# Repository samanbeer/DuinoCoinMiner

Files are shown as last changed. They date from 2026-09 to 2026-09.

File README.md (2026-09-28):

# DuinoCoinMiner



- **What is it?** It is a small PCB board with XIAO ESP32-C3 as main MCU for controlling 6 ATmega328P chips
- **What does it do?** It mines crypto currency called Duino Coin. Which is a specialized coin that can be mined on any device like arduinos and lot more. You read about it on their [site](duinocoin.com)

## Project Gallery

### 3D PCB Renders

<p align="center">
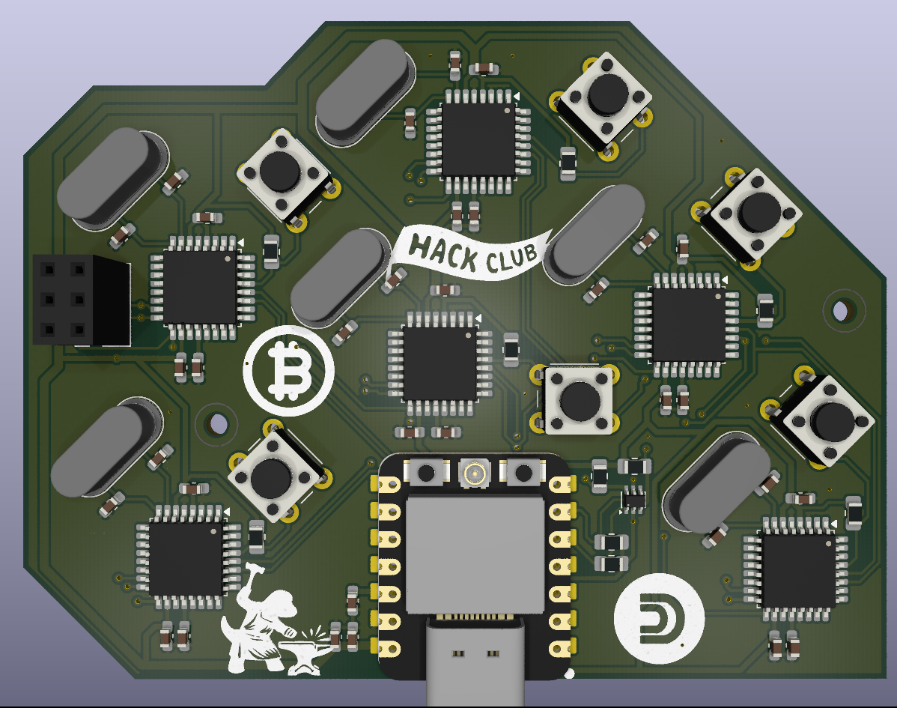
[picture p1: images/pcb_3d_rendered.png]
Rendered PCB Top
  
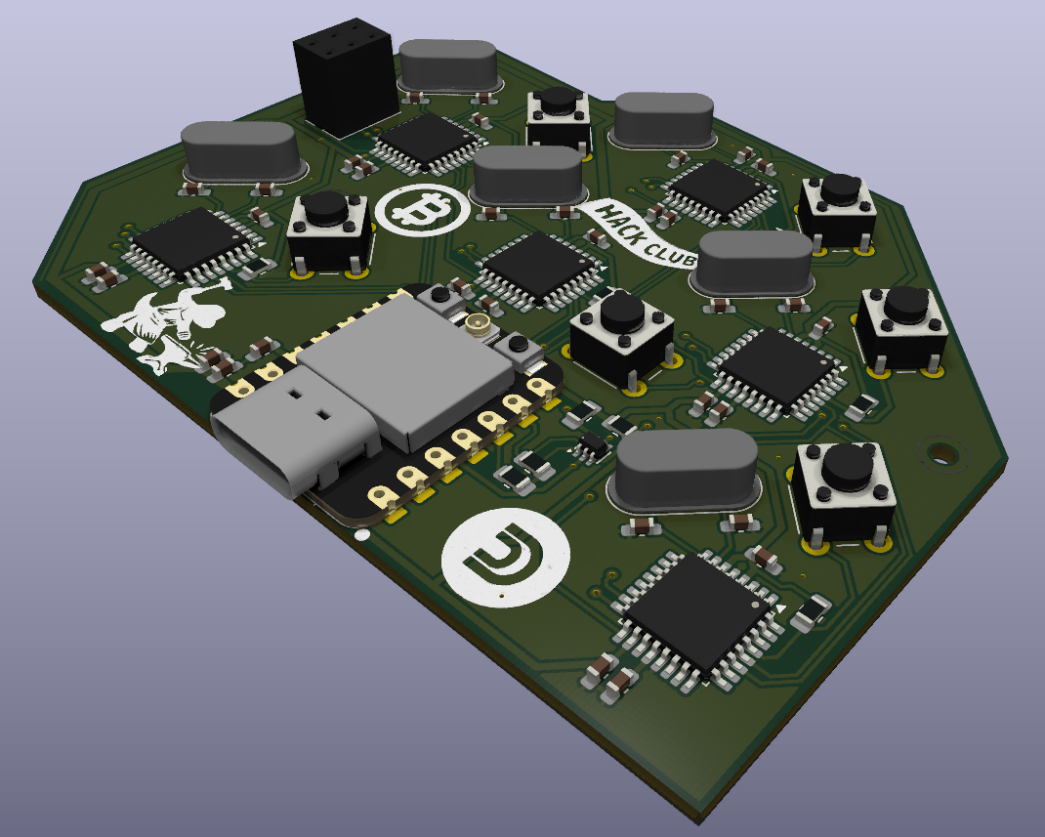
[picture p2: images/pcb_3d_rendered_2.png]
Rendered PCB Angle
  
</p>

### PCB Schematic and layout

<p align="center">
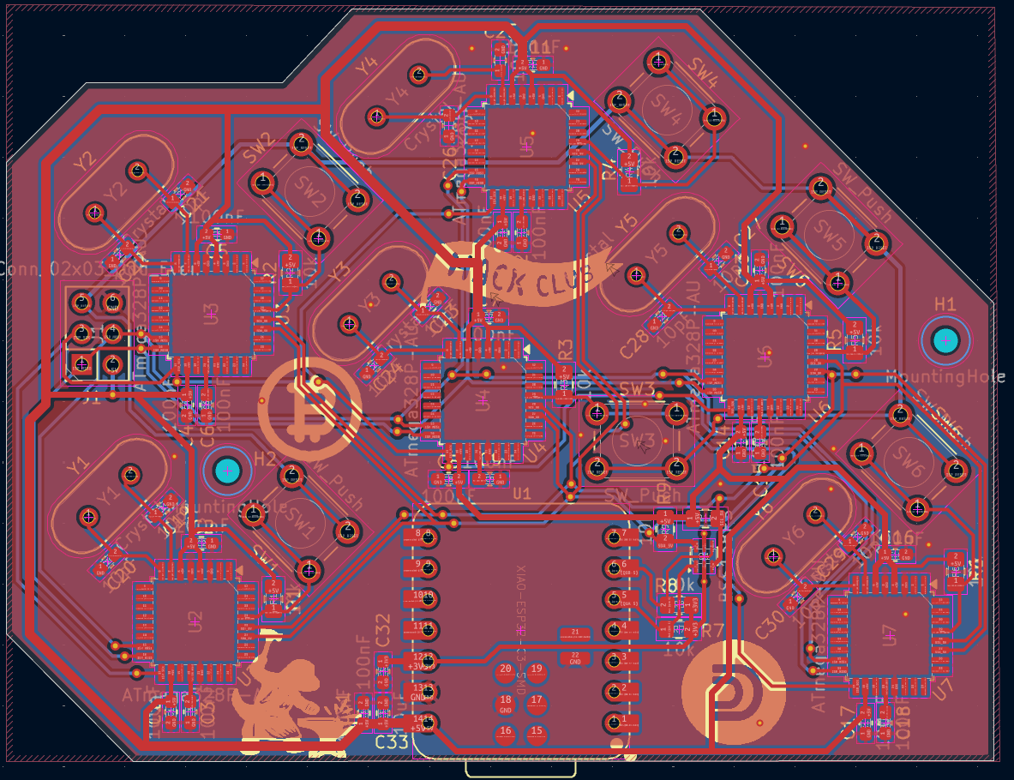
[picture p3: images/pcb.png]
PCB Layout
  
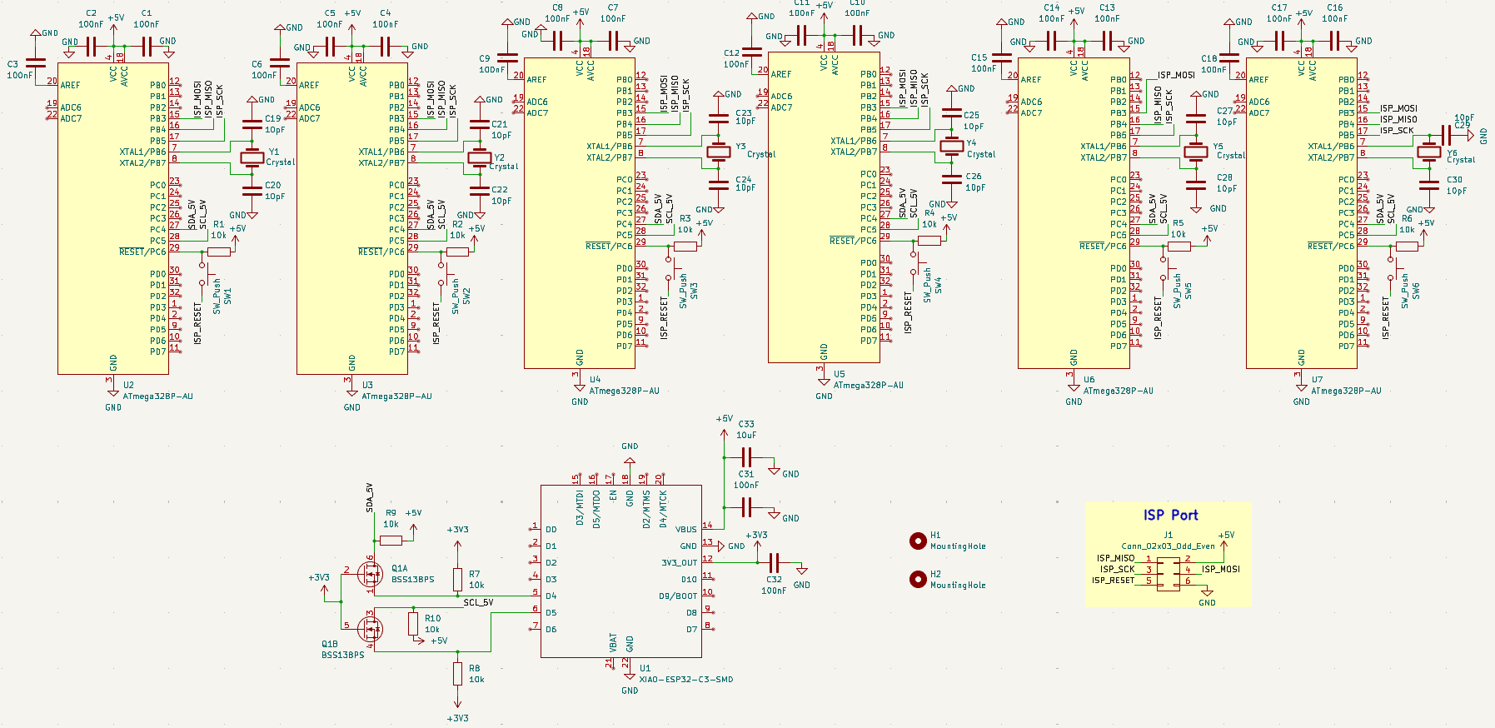
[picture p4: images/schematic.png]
Schematic Diagram
  
</p>

### 3D Enclosure (Fusion 360)

*3D printable case made in Fusion 360. All CAD and 3D model files (`.f3z`, `.step`) are in the [`CAD/`](CAD/) folder.*

<p align="center">
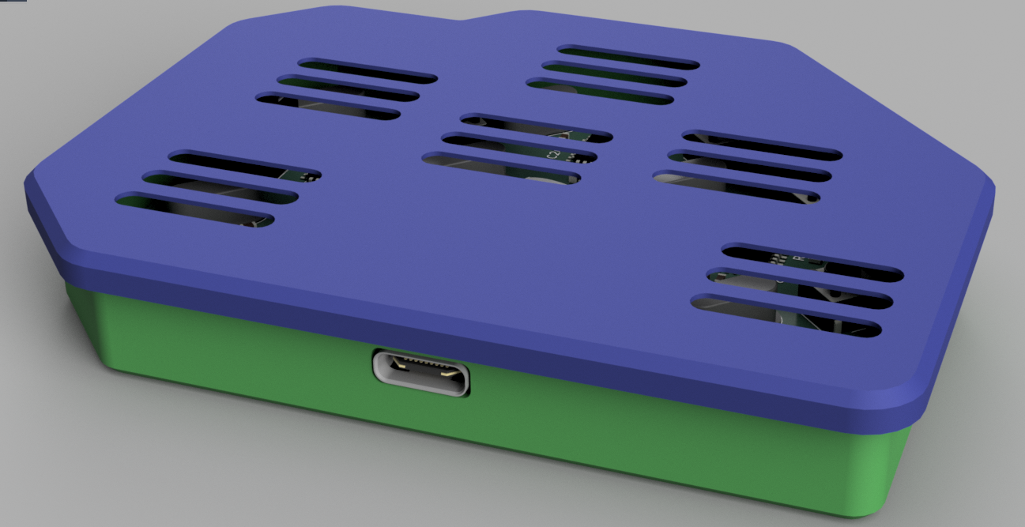
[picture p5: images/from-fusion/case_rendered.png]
Fusion 360 Case Render Front
  
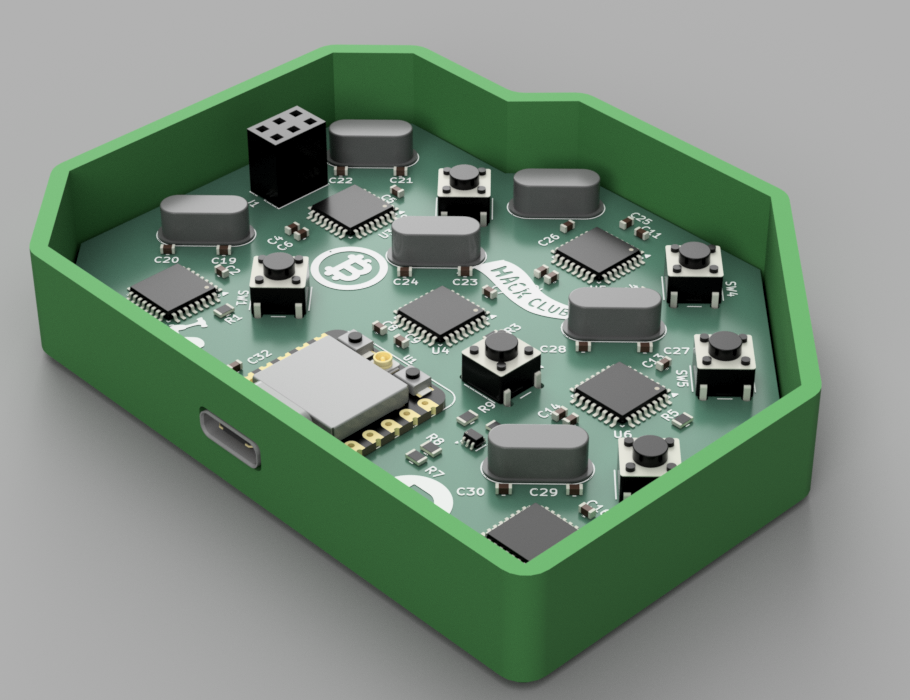
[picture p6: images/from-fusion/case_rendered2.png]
Fusion 360 Case Render Rear
  
</p>

<p align="center">
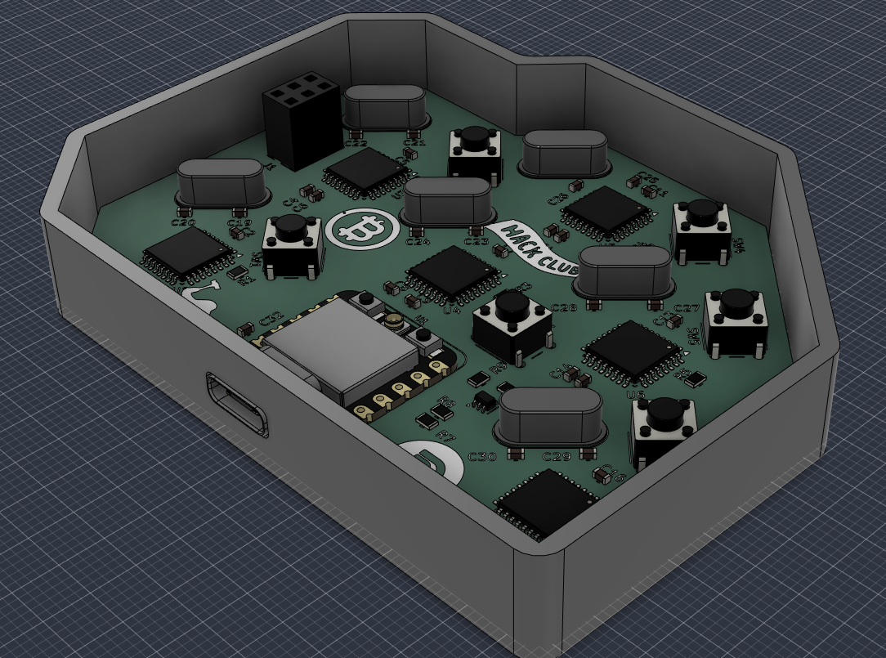
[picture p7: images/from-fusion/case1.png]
Fusion 360 Case Internal Assembly
  
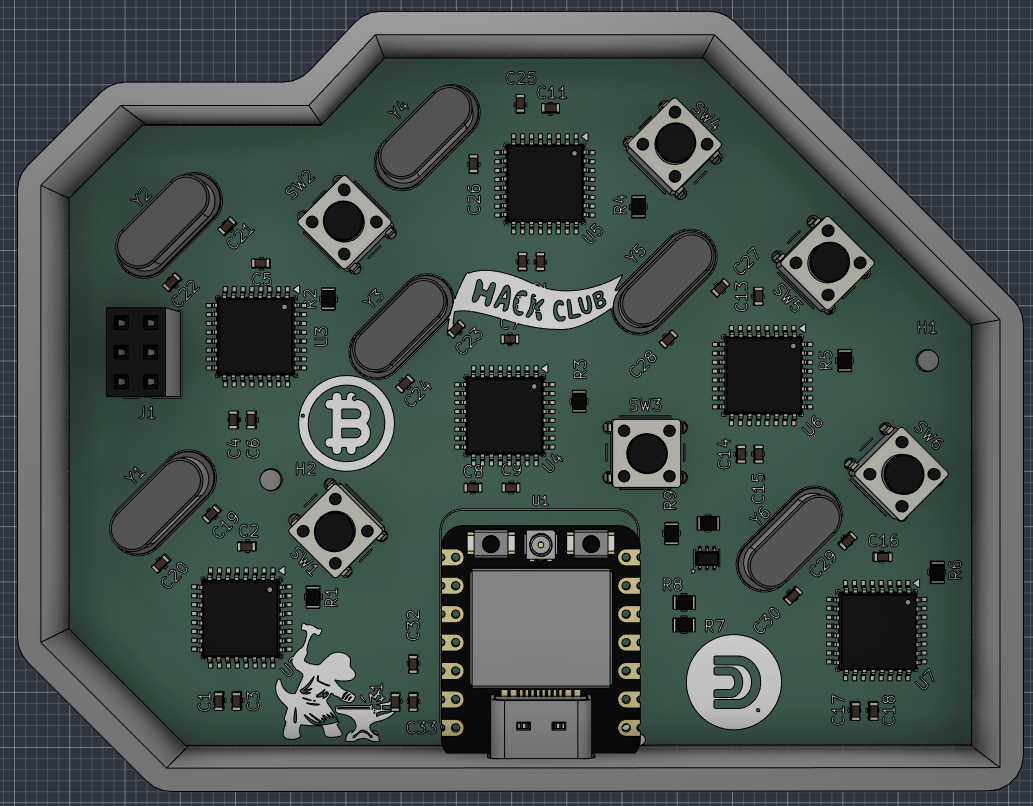
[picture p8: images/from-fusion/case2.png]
Fusion 360 Internal PCB Placement
  
</p>

<p align="center">
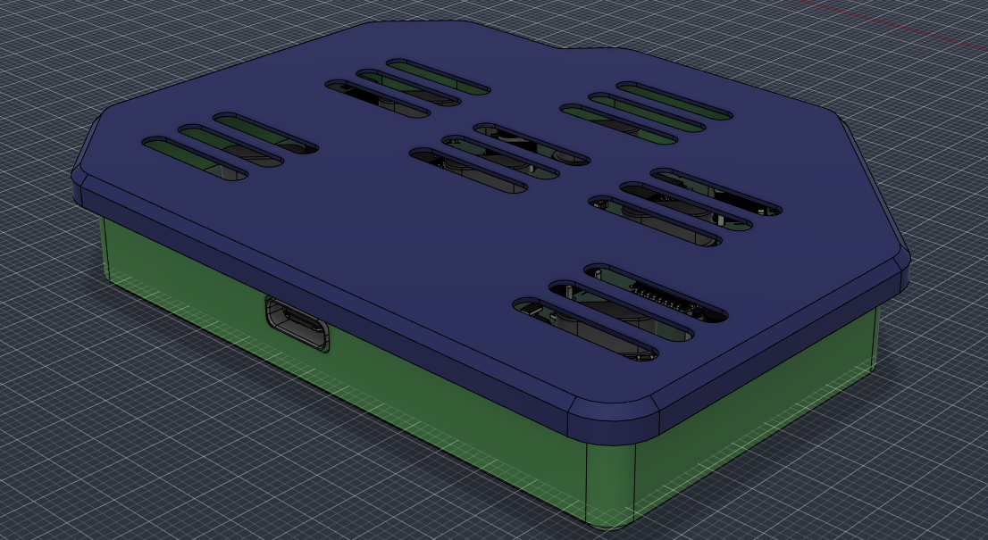
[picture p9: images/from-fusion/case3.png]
Fusion 360 Case Model View
  
</p>

---

### Required Tools & Materials

- Soldering iron
- Good solder wire
- Solder flux 
- small tweezers for picking small components like resistors and condenzators 
- 3D Printer for printing case from /cad folder

### Assembly Steps

1. **Start with the chips:**
   
   - **ATmega328P-AU** and **BSS138PS** .
   - It is best to solder these first while the board is clear of other bigger things.

2. **SMD Components:**
- - C1–C18, C31, C32 
  - C19–C30 
  - C33
  - R1–R10
3. **Main MCU:**
-     **Seeed Studio XIAO ESP32-C3**.
  - Solder the XIAO directly onto the PCB pads or solder pin headers so you can plug it in(not recommended)
4. **THT Components:**
-     **Crystals:** 20MHz crystals. Clip the leads, and solder from the bottom side.
  - **Switches:** 6x6mm reset buttons. Snap them into their holes and solder.
  - **ISP pin Header:** 2x3 pin header. Solder it to the board.
5. **Enclosure Assembly:**
-     3D print the bottom base (`case.step`) and the lid (`case_lid.step`). Files are in the /CAD folder.
  - Place PCB inside the bottom enclosure, with XIAO USB-C port aligned to the hole, and attach the lid.

---

## Firmware

Firmware files are located in "firmware" folder with README.md that contains guide how to flash the chips correclty and what you will need to install.

## BOM

| Reference | amount | Value / Component | Footprint / Package | Link | Cost (USD) |
| --- |:---:|:--- |:--- |:--- |:---:|
| **C1-C18, C31 and C32** | 20 | 100nF 50V | 0603 SMD | [TME Link](https://www.tme.eu/cz/details/0603b104k500ct/kondenzatory-mlcc-smd/walsin/) | $0.40 |
| **C19-C30** | 12 | 22pF 50V | 0603 SMD | [TME Link](https://www.tme.eu/cz/details/cc0603jrnpo9bn220/kondenzatory-mlcc-smd/yageo/) | $0.36 |
| **C33** | 1 | 10µF 10V | 0603 SMD | [TME Link](https://www.tme.eu/cz/details/lmk107bj106maltd/kondenzatory-mlcc-smd/taiyo-yuden/) | $0.12 |
| **J1** | 1 | 2x3 Pin Header | Pin header 2x03 (2.54mm) | [TME Link](https://www.tme.eu/cz/details/bl2-06g/dutinkove-listy/connfly/) | $0.35 |
| **Q1** | 1 | BSS138PS mosfet | SOT-363 | [TME Link](https://www.tme.eu/cz/details/bss138ps.115/tranzistory-s-polem-n-kanalove-smd/nexperia/) | $0.45 |
| **R1-R10** | 10 | 10kΩ | 0805 SMD | [TME Link](https://www.tme.eu/cz/details/crcw080510k0fkea/rezistory-smd/vishay/) | $0.14 |
| **SW1–SW6** | 6 | Switch (6x6mm, Height=5mm) | SW_PUSH_6mm_H5mm THT | [TME Link](https://www.tme.eu/cz/details/1825910-6/mikroprepninace-tact-tht/te-connectivity/) | $0.90 |
| **U1** | 1 | Seeed Studio XIAO ESP32-C3 | XIAO DIP/SMD Module | [TME Link](https://www.tme.eu/cz/details/seeed-113991054/vyvojove-kity-ostatni/seeed-studio/113991054/) | $6.36 |
| **U2-U7** | 6 | ATmega328P-AU (**20mHz**)  | TQFP-32 | [TME Link](https://www.tme.eu/cz/details/atmega328p-au/mikrokontrolery-avr/microchip-technology/) | $14.70 |
| **Y1-Y6** | 6 | 20MHz Quartz Crystal | HC-49/U THT | [TME Link](https://www.tme.eu/cz/details/49-20.000maaj-b/krystalove-rezonatory-tht/qst/) | $1.80 |
| **PCB** | 1 | 2 Layers | | [JLCPCB](https://jlcpcb.com) | ±$14 |
| **Shipping** | | Total Shipping | | TME and JLCPCB | $12.9 |
| **Total** | | | | | **52.48**  |

JLCPCB cart:



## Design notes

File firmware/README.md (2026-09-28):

# Firmware for DuinoCoinMiner

## 1. ATmega328P Nodes (`DuinoCoin_Arduino_Slave`)

### Required Arduino Libraries:

Install these libraries in your Arduino IDE via Library Manager or GitHub:

- [DuinoCoin](https://github.com/ricaun/arduino-DuinoCoin) (DUCO-S1A hashing engine)
- [ArduinoUniqueID](https://github.com/ricaun/ArduinoUniqueID) (Chip identifier)
- [StreamJoin](https://github.com/ricaun/StreamJoin) (StreamString for AVR)

### Flashing via ICSP (Connector J1):

1. Use an ISP programmer (e.g. **USBasp** or an **Arduino as ISP**).
2. Install the **[MiniCore](https://github.com/MCUdude/MiniCore)** board package in Arduino IDE:
   - Add `https://mcudude.github.io/MiniCore/package_MCUdude_MiniCore_index.json` to Additional Boards Manager URLs.
3. In **Tools** menu select:
   - **Board:** ATmega328P
   - **Clock:** External 20 MHz
   - **BOD:** 2.7V (or 4.3V)
   - **Compiler LTO:** Enabled
4. Click **Tools -> Burn Bootloader** to set the correct fuses for the 20MHz crystal.
5. Open `firmware/DuinoCoin_Arduino_Slave/DuinoCoin_Arduino_Slave.ino` and click **Sketch -> Upload Using Programmer**.

---

## 2. Master (`DuinoCoin_Esp_Async_Master`)

### Configuration:

Open `firmware/DuinoCoin_Esp_Async_Master/DuinoCoin_Esp_Async_Master.ino` and set:

```cpp
const char* ssid          = "Your_WiFi_SSID";      // Your Wi-Fi network name
const char* password      = "Your_WiFi_Password";  // Your Wi-Fi network password
const char* ducouser      = "Your_Username";       // Your Duino-Coin wallet username
const char* rigIdentifier = "DuinoMiner-6x";       // Custom name shown in web dashboard
```

### Required Arduino Libraries:

- [ArduinoJson](https://github.com/bblanchon/ArduinoJson) (v6.x)
- [AsyncTCP](https://github.com/me-no-dev/AsyncTCP)
- [ESPAsyncWebServer](https://github.com/me-no-dev/ESPAsyncWebServer)

### Flashing via USB-C:

1. Connect the Seeed Studio XIAO ESP32-C3 directly via USB-C to your computer.
2. In Arduino IDE:
   - Board: **XIAO_ESP32C3** (from Seeed Studio ESP32 boards package or official ESP32 by Espressif)
   - Port: Select the corresponding COM port
3. Click **Upload**.

---

## Upstream Sources & Credits

- **I2C Rig Architecture & Firmware:** [ricaun/DuinoCoinI2C](https://github.com/ricaun/DuinoCoinI2C) (Luiz H. Cassettari)
- **Official Duino-Coin Project:** [revoxhere/duino-coin](https://github.com/revoxhere/duino-coin)
- **Hashing Engine:** [ricaun/arduino-DuinoCoin](https://github.com/ricaun/arduino-DuinoCoin)
- **AVR 20MHz Core:** [MCUdude/MiniCore](https://github.com/MCUdude/MiniCore)

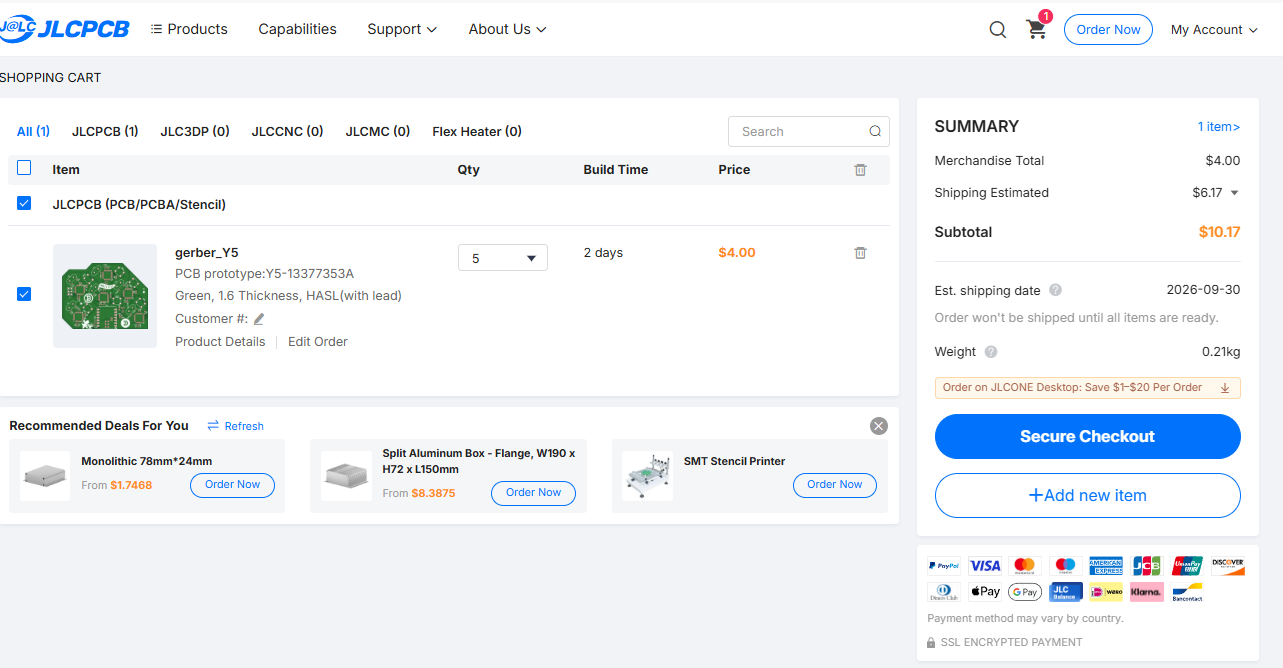
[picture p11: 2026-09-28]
images/jlcpcb_cart.png

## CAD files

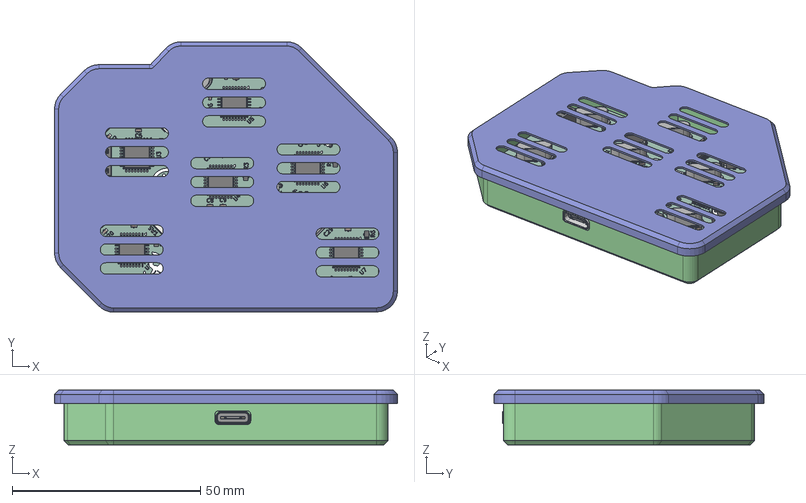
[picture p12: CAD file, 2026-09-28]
CAD/everything_assembled_CASE+PCB.step.step
91.2 x 71.9 x 14.5 mm
C_0603_1608Metric_1 x 33
Crystal_HC49-4H_Vertical_1 x 6
R_0805_2012Metric_1 x 10
TQFP-32_7x7mm_P0.8mm_1 x 6
SOT-363_SC-70-6_1
SW_PUSH_6mm_h5mm_1 x 6
PinSocket_2x03_P2.54mm_Vertical_1
BOSS-EXTRUDE14_8_
BOSS-EXTRUDE7_4_
BOSS-EXTRUDE7_3_
BOSS-EXTRUDE14_4_
BOSS-EXTRUDE14_2_
BOSS-EXTRUDE14_11_
BOSS-EXTRUDE7_7_
BOSS-EXTRUDE14_9_
BOSS-EXTRUDE14_3_
BOSS-EXTRUDE14_7_
MIRROR2
BOSS-EXTRUDE14_5_
BOSS-EXTRUDE14_12_
BOSS-EXTRUDE7_8_
BOSS-EXTRUDE7_1_
BOSS-EXTRUDE14_10_
BOSS-EXTRUDE7_9_
BOSS-EXTRUDE14_6_
BOSS-EXTRUDE14_1_
BOSS-EXTRUDE7_6_
BOSS-EXTRUDE7_2_
CUT-EXTRUDE5
BOSS-EXTRUDE7_5_
U.FL Connector v1
Button (1) x 2
Shield
Duino_miner_silkscreen
Duino_miner_PCB

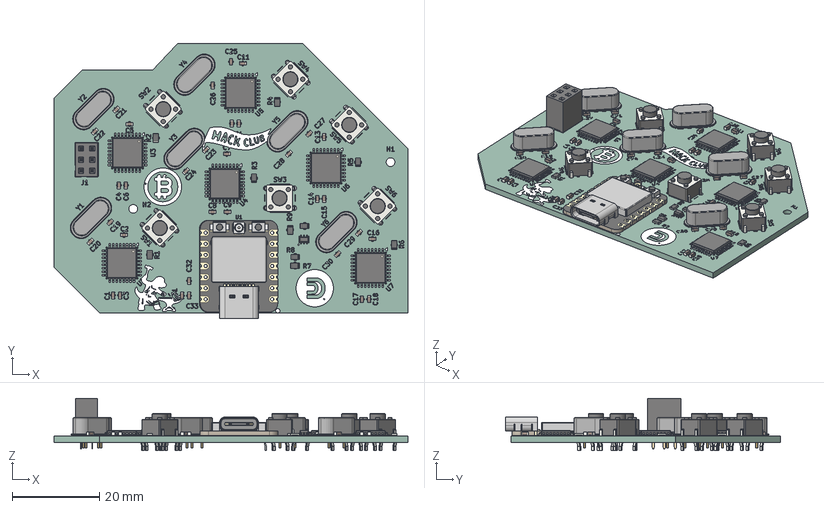
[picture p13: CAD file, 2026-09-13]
PCB/PCB.step
81.1 x 63.0 x 12.0 mm
C_0603_1608Metric x 33
Crystal_HC49-4H_Vertical x 6
R_0805_2012Metric x 10
TQFP-32_7x7mm_P0.8mm x 6
SOT-363_SC-70-6
SW_PUSH_6mm_h5mm x 6
PinSocket_2x03_P2.54mm_Vertical
BOSS-EXTRUDE14_8_
BOSS-EXTRUDE7_4_
BOSS-EXTRUDE7_3_
BOSS-EXTRUDE14_4_
BOSS-EXTRUDE14_2_
BOSS-EXTRUDE14_11_
BOSS-EXTRUDE7_7_
BOSS-EXTRUDE14_9_
BOSS-EXTRUDE14_3_
BOSS-EXTRUDE14_7_
MIRROR2
BOSS-EXTRUDE14_5_
BOSS-EXTRUDE14_12_
BOSS-EXTRUDE7_8_
BOSS-EXTRUDE7_1_
BOSS-EXTRUDE14_10_
BOSS-EXTRUDE7_9_
BOSS-EXTRUDE14_6_
BOSS-EXTRUDE14_1_
BOSS-EXTRUDE7_6_
BOSS-EXTRUDE7_2_
CUT-EXTRUDE5
BOSS-EXTRUDE7_5_
U.FL Connector v1
Button (1) x 2
Shield
Duino_miner_silkscreen
Duino_miner_PCB

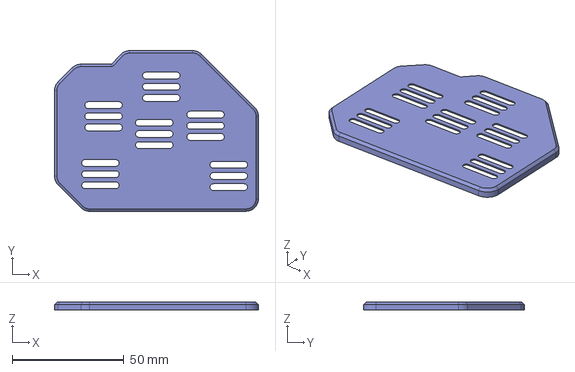
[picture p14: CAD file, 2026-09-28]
CAD/case_lid.step
91.2 x 71.9 x 3.50 mm

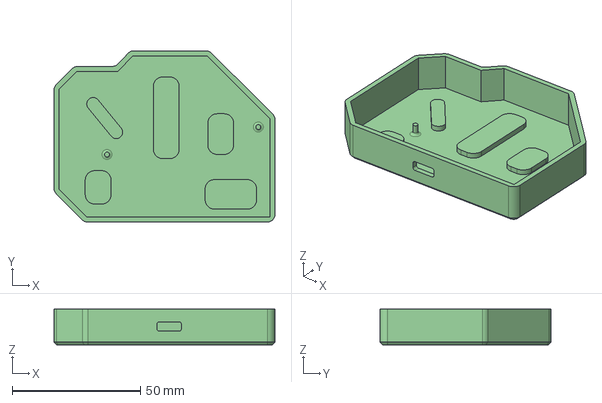
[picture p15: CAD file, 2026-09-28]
CAD/case.step
86.1 x 66.8 x 14.0 mm

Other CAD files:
CAD/CASE.f3z

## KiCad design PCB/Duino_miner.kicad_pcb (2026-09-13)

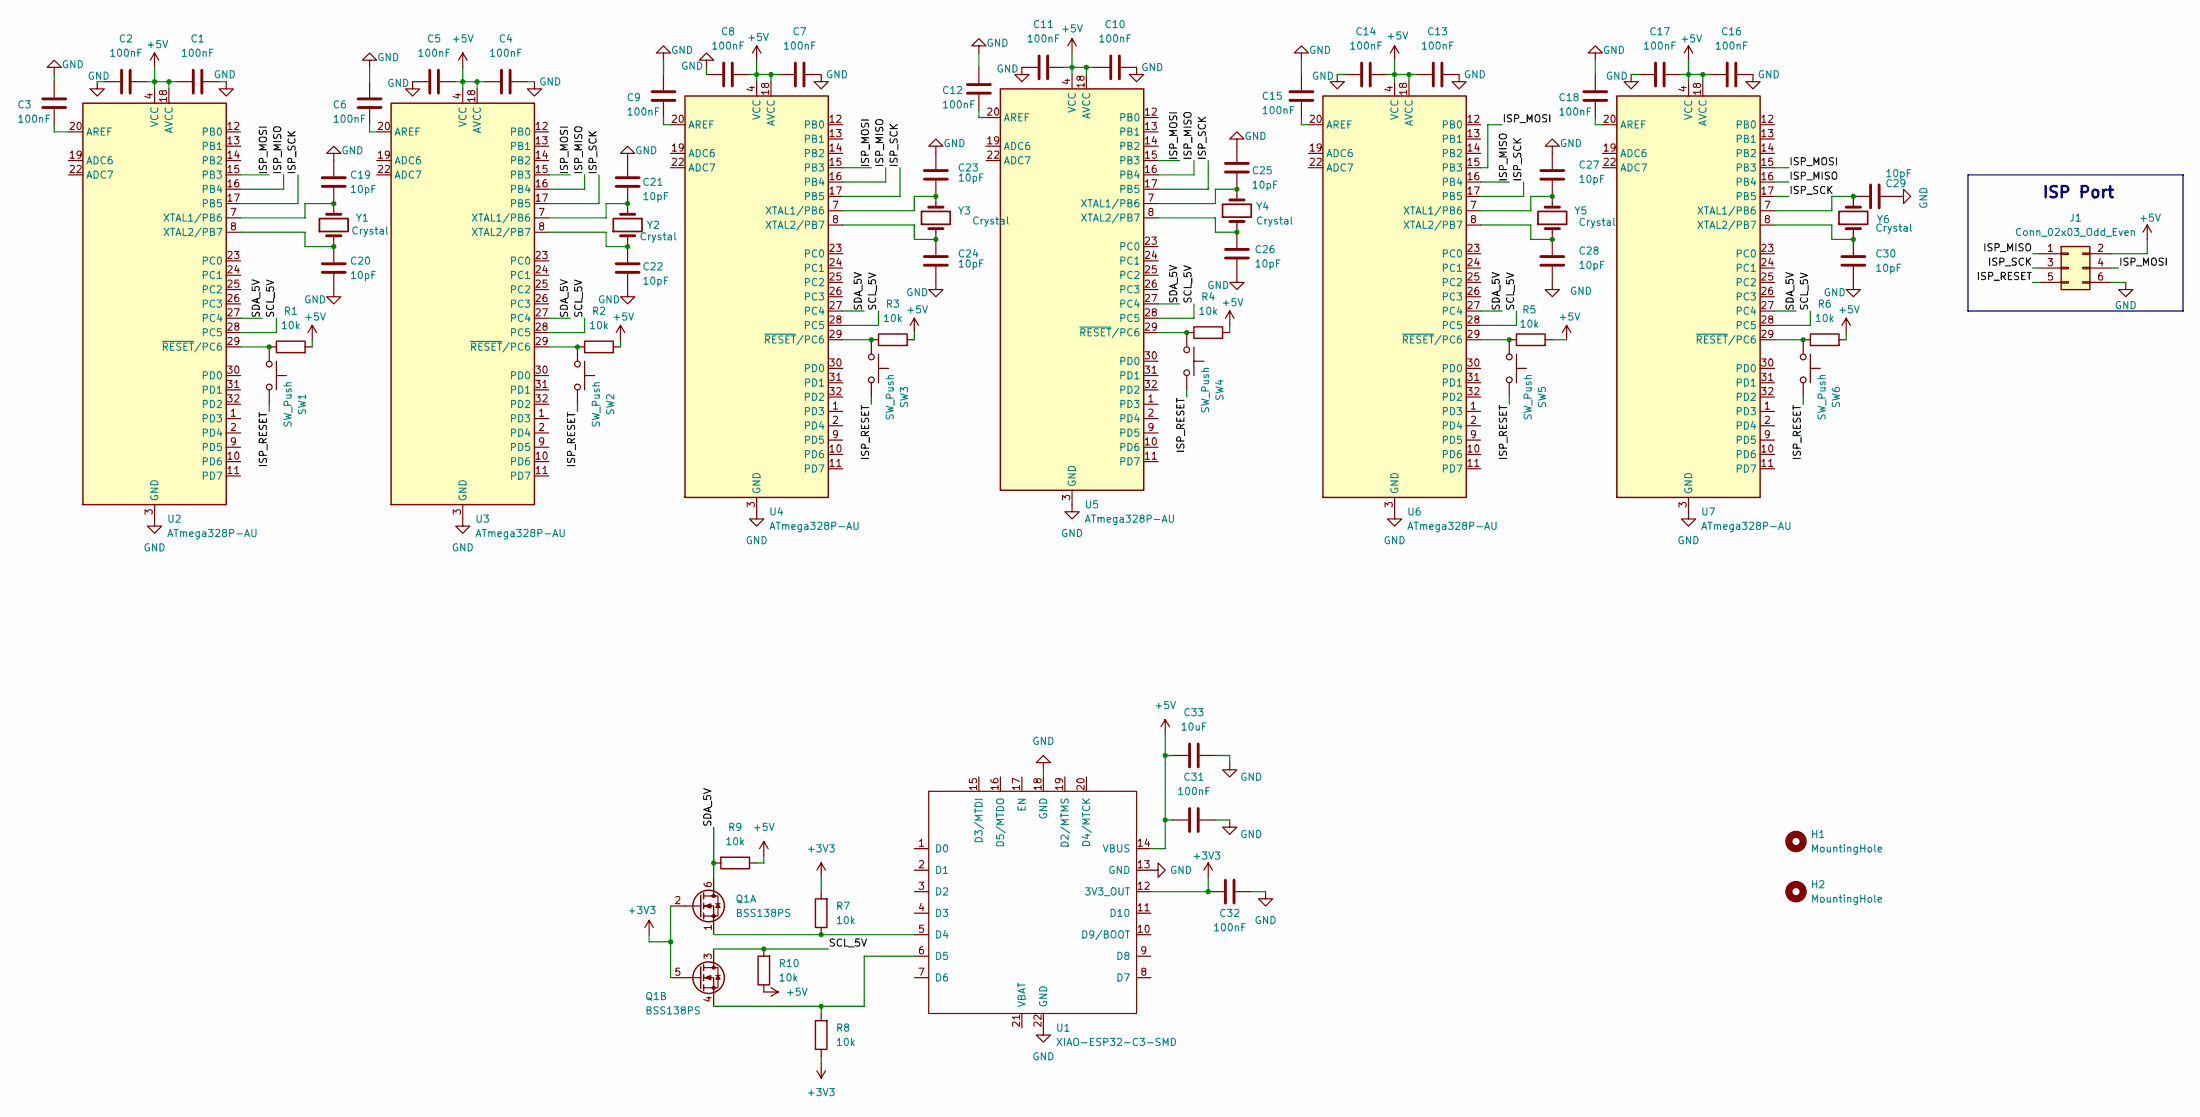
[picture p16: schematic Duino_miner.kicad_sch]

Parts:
C1, C2, C3, C4, C5, C6, C7, C8, C9, C10, C11, C12, C13, C14, C15, C16, C17, C18, C31, C32: 100nF; C_0603_1608Metric_Pad1.08x0.95mm_HandSolder
C19, C20, C21, C22, C23, C24, C25, C26, C27, C28, C29, C30: 10pF; C_0603_1608Metric_Pad1.08x0.95mm_HandSolder
C33: 10uF; C_0603_1608Metric_Pad1.08x0.95mm_HandSolder
H1, H2: MountingHole; MountingHole_2mm
J1: Conn_02x03_Odd_Even; PinSocket_2x03_P2.54mm_Vertical
Q1: BSS138PS; SOT-363_SC-70-6
R1, R2, R3, R4, R5, R6, R7, R8, R9, R10: 10k; R_0805_2012Metric_Pad1.20x1.40mm_HandSolder
SW1, SW2, SW3, SW4, SW5, SW6: SW_Push; SW_PUSH_6mm_H5mm
U1: XIAO-ESP32-C3-SMD; XIAO-ESP32-C3-DIP-SMD
U2, U3, U4, U5, U6, U7: ATmega328P-AU; TQFP-32_7x7mm_P0.8mm
Y1, Y2, Y3, Y4, Y5, Y6: Crystal; Crystal_HC49-4H_Vertical

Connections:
+3V3: C32.1, Q1.2 (G), Q1.5 (G), R7.2, R8.1, U1.12 (3V3_OUT)
+5V: C1.1, C2.2, C4.1, C5.2, C7.1, C8.2, C10.1, C11.2, C13.1, C14.2, C16.1, C17.2, C31.1, C33.1, J1.2, R1.2, R2.2, R3.2, R4.2, R5.2, R6.2, R9.1, R10.1, U1.14 (VBUS), U2.4 (VCC), U2.6 (VCC), U2.18 (AVCC), U3.4 (VCC), U3.6 (VCC), U3.18 (AVCC), U4.4 (VCC), U4.6 (VCC), U4.18 (AVCC), U5.4 (VCC), U5.6 (VCC), U5.18 (AVCC), U6.4 (VCC), U6.6 (VCC), U6.18 (AVCC), U7.4 (VCC), U7.6 (VCC), U7.18 (AVCC)
/ISP_MISO: J1.1, U2.16 (PB4), U3.16 (PB4), U4.16 (PB4), U5.16 (PB4), U6.16 (PB4), U7.16 (PB4)
/ISP_MOSI: J1.4, U2.15 (PB3), U3.15 (PB3), U4.15 (PB3), U5.15 (PB3), U6.15 (PB3), U7.15 (PB3)
/ISP_RESET: J1.5, SW1.2, SW2.2, SW3.2, SW4.2, SW5.2, SW6.2
/ISP_SCK: J1.3, U2.17 (PB5), U3.17 (PB5), U4.17 (PB5), U5.17 (PB5), U6.17 (PB5), U7.17 (PB5)
/SCL_5V: Q1.3 (D), R10.2, U2.28 (PC5), U3.28 (PC5), U4.28 (PC5), U5.28 (PC5), U6.28 (PC5), U7.28 (PC5)
/SDA_5V: Q1.6 (D), R9.2, U2.27 (PC4), U3.27 (PC4), U4.27 (PC4), U5.27 (PC4), U6.27 (PC4), U7.27 (PC4)
GND: C1.2, C2.1, C3.1, C4.2, C5.1, C6.1, C7.2, C8.1, C9.1, C10.2, C11.1, C12.1, C13.2, C14.1, C15.1, C16.2, C17.1, C18.1, C19.2, C20.1, C21.2, C22.1, C23.2, C24.1, C25.2, C26.1, C27.2, C28.1, C29.2, C30.1, C31.2, C32.2, C33.2, J1.6, U1.13 (GND), U1.18 (GND), U1.22 (GND), U2.3 (GND), U2.5 (GND), U2.21 (GND), U3.3 (GND), U3.5 (GND), U3.21 (GND), U4.3 (GND), U4.5 (GND), U4.21 (GND), U5.3 (GND), U5.5 (GND), U5.21 (GND), U6.3 (GND), U6.5 (GND), U6.21 (GND), U7.3 (GND), U7.5 (GND), U7.21 (GND)
unnamed: Q1.1 (S), R7.1, U1.5 (D4)
unnamed: Q1.4 (S), R8.2, U1.6 (D5)
unnamed: C3.2, U2.20 (AREF)
unnamed: C19.1, U2.7 (XTAL1/PB6), Y1.2
unnamed: C20.2, U2.8 (XTAL2/PB7), Y1.1
unnamed: R1.1, SW1.1, U2.29 (~RESET/PC6)
unnamed: C6.2, U3.20 (AREF)
unnamed: C21.1, U3.7 (XTAL1/PB6), Y2.2
unnamed: C22.2, U3.8 (XTAL2/PB7), Y2.1
unnamed: R2.1, SW2.1, U3.29 (~RESET/PC6)
unnamed: C9.2, U4.20 (AREF)
unnamed: C23.1, U4.7 (XTAL1/PB6), Y3.2
unnamed: C24.2, U4.8 (XTAL2/PB7), Y3.1
unnamed: R3.1, SW3.1, U4.29 (~RESET/PC6)
unnamed: C12.2, U5.20 (AREF)
unnamed: C25.1, U5.7 (XTAL1/PB6), Y4.2
unnamed: C26.2, U5.8 (XTAL2/PB7), Y4.1
unnamed: R4.1, SW4.1, U5.29 (~RESET/PC6)
unnamed: C15.2, U6.20 (AREF)
unnamed: C27.1, U6.7 (XTAL1/PB6), Y5.2
unnamed: C28.2, U6.8 (XTAL2/PB7), Y5.1
unnamed: R5.1, SW5.1, U6.29 (~RESET/PC6)
unnamed: C18.2, U7.20 (AREF)
unnamed: C29.1, U7.7 (XTAL1/PB6), Y6.2
unnamed: C30.2, U7.8 (XTAL2/PB7), Y6.1
unnamed: R6.1, SW6.1, U7.29 (~RESET/PC6)

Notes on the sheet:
ISP Port

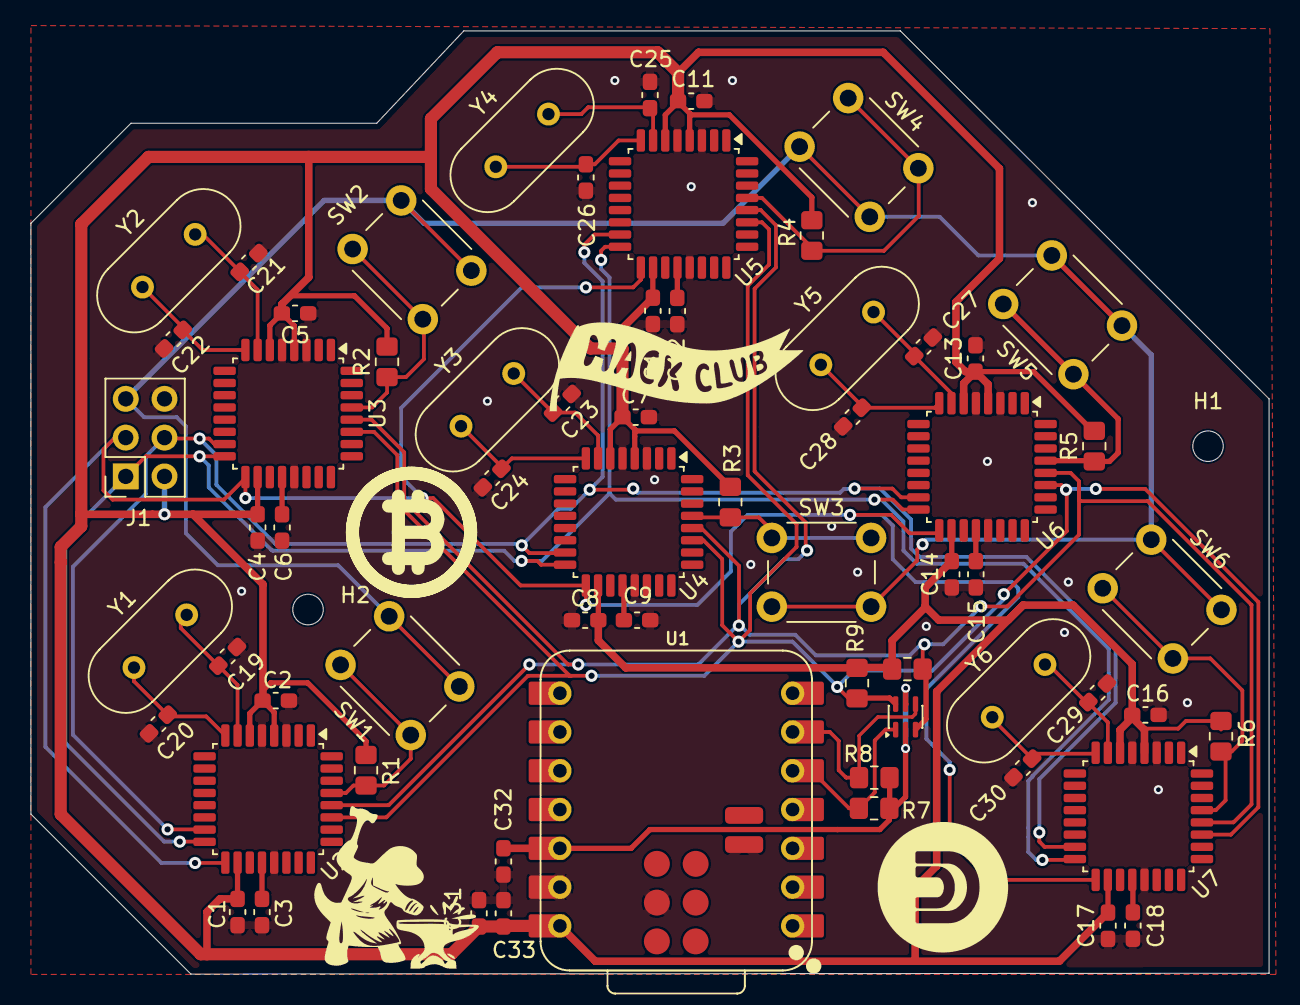
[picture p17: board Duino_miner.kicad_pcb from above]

Board: 2 copper layers, 81.1 x 61.8 mm, 66 parts (0 on the bottom side), 35 nets.

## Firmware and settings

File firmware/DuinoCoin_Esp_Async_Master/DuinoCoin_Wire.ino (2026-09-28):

/*
  DuinoCoin_Wire.ino
  created 10 05 2021
  by Luiz H. Cassettari
*/

#include <Wire.h>

#if ESP8266
#define SDA 4 // D2 - A4 - GPIO4
#define SCL 5 // D1 - A5 - GPIO5
#endif

#if defined(CONFIG_IDF_TARGET_ESP32C3) || defined(ARDUINO_XIAO_ESP32C3) || defined(ARDUINO_SEEED_XIAO_ESP32C3)
#define SDA 6 // D4 on XIAO ESP32-C3
#define SCL 7 // D5 on XIAO ESP32-C3
#elif defined(ESP32)
#define SDA 21
#define SCL 22
#endif

#define WIRE_CLOCK 100000
#define WIRE_MAX 32

void wire_setup()
{
  //pinMode(SDA, INPUT_PULLUP);
  //pinMode(SCL, INPUT_PULLUP);
  wire_start();
  wire_readAll();
}

void wire_start()
{
  Wire.begin(SDA, SCL);
  Wire.setClock(WIRE_CLOCK);
}

void wire_readAll()
{
  for (byte address = 1; address < WIRE_MAX; address++ )
  {
    if (wire_exists(address))
    {
      Serial.print("Address: ");
      Serial.println(address);
      wire_readLine(address);
    }
  }
}

void wire_SendAll(String message)
{
  for (byte address = 1; address < WIRE_MAX; address++ )
  {
    if (wire_exists(address))
    {
      Serial.print("Address: ");
      Serial.println(address);
      Wire_sendln(address, message);
    }
  }
}

boolean wire_exists(byte address)
{
  wire_start();
  Wire.beginTransmission(address);
  byte error = Wire.endTransmission();
  return (error == 0);
}

void wire_sendJob(byte address, String lastblockhash, String newblockhash, int difficulty)
{
  String job = lastblockhash + "," + newblockhash + "," + difficulty;
  Wire_sendln(address, job);
}

void Wire_sendln(byte address, String message)
{
  Wire_send(address, message + "\n");
}

void Wire_send(byte address, String message)
{
  wire_start();
  for (int i = 0; i < message.length(); i++)
  {
    Wire.beginTransmission(address);
    Wire.write(message.charAt(i));
    Wire.endTransmission();
  }
}

String wire_readLine(int address)
{
  wire_runEvery(0);
  char end = '\n';
  String str = "";
  boolean done = false;
  wire_start();
  while (!done)
  {
    Wire.requestFrom(address, 1);
    if (Wire.available())
    {
      char c = Wire.read();
      //Serial.print(c);
      if (c == end)
      {
        break;
        done = true;
      }
      str += c;
    }
    if (wire_runEvery(2000)) break;
  }
  //str += end;
  return str;
}

boolean wire_runEvery(unsigned long interval)
{
  static unsigned long previousMillis = 0;
  unsigned long currentMillis = millis();
  if (currentMillis - previousMillis >= interval)
  {
    previousMillis = currentMillis;
    return true;
  }
  return false;
}

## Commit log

2026-09-05 Schematic Done, starting PCB
    [Duino_miner.kicad_pcb, Duino_miner.kicad_sch]
2026-09-05 2 Chips done
    [Duino_miner.kicad_pcb]
2026-09-13 PCB done, yepeee
    [Duino_miner-B_Cu.gbr, Duino_miner-B_Mask.gbr, Duino_miner-B_Paste.gbr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]
